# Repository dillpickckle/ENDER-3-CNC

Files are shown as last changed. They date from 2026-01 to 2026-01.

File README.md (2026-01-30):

This is an affordable mini CNC mill built from Ender 3 parts. It’s suitable for tasks such as milling, engraving, drawing, and PCB fabrication. The machine is driven by NEMA 17 motors, belts, and two lead screws. It uses an old Dremel that I had lying around as a spindle, and I also made an enclosure out of acrylic and plywood. It use klipper software to run, with a "Klipperized" post-processor to make work on Fusion 360 CAM. Credit to @IMLAB, @SGD_Knuffel, and the team at Ender CNC for providing most of the printables. I used a mix of those files to create an Ender-3 CNC that I felt was most optimized. I made this so I can level up my future projects with acrylic and aluminum parts without having to pay a bunch to get them milled. I also hope to continue working on improving those files in the coming weeks and possibly even mill the sides out of aluminum. Other than using those files, I did not follow any specific guide and did everything else myself. 

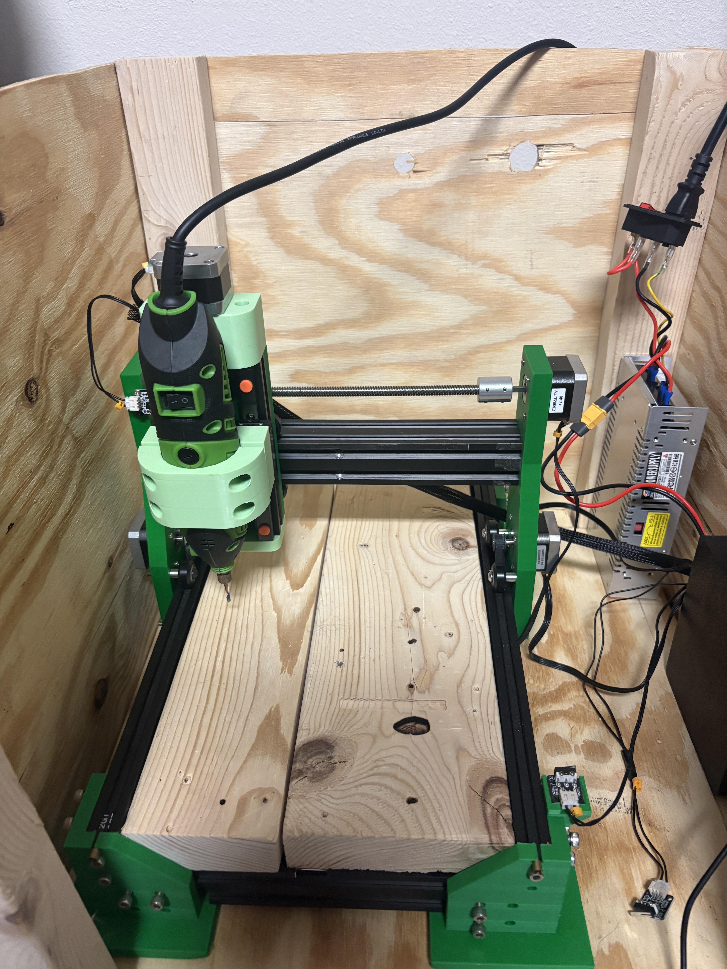
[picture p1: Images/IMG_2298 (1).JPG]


Wiring Diagram 

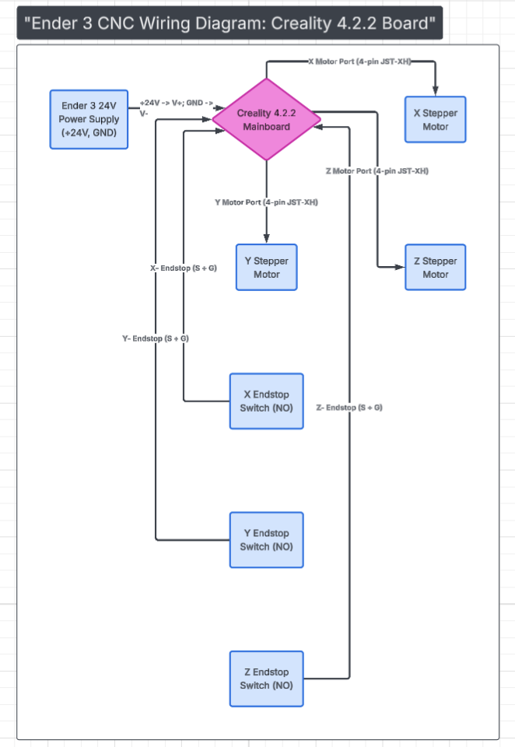
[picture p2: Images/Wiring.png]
Wiring


As you can see, it's pretty simple. Just connect the xyz ports to their respective motors and do the same with the endstops. Also, make sure to connect the board to the ender power supply. 

BOM: 

1 x Ender 3 

2 x Linear Rails 150mm MGN12H [Link for Amazon](https://www.amazon.com/uxcell-Sliding-Carriage-Plastic-Printers/dp/B0D54L8LH4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)

1 x  Mscrew assortment kit  [Link for Amazon](https://www.amazon.com/uxcell-Sliding-Carriage-Plastic-Printers/dp/B0D54L8LH4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)

1 x Brass heat threaded insert assortment kit [Link for Amazon](https://www.amazon.com/Ktehloy-Threaded-Assortment-Printing-Components/dp/B0CLKDPN65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)

32 x M5 T-Nuts [Link for Amazon](https://www.amazon.com/Glarks-European-Assortment-Aluminum-Profile/dp/B07DFG2Y4Q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)

1 x Appropriate Spindle (I used an old Dremel, which I had lying around)

2 x ball bearings (I used ones that came on ender 3 tensioner)  

2 x GT2 clip [File](https://www.thingiverse.com/thing:2523813)

All 3d Printed Parts in CAD Folder

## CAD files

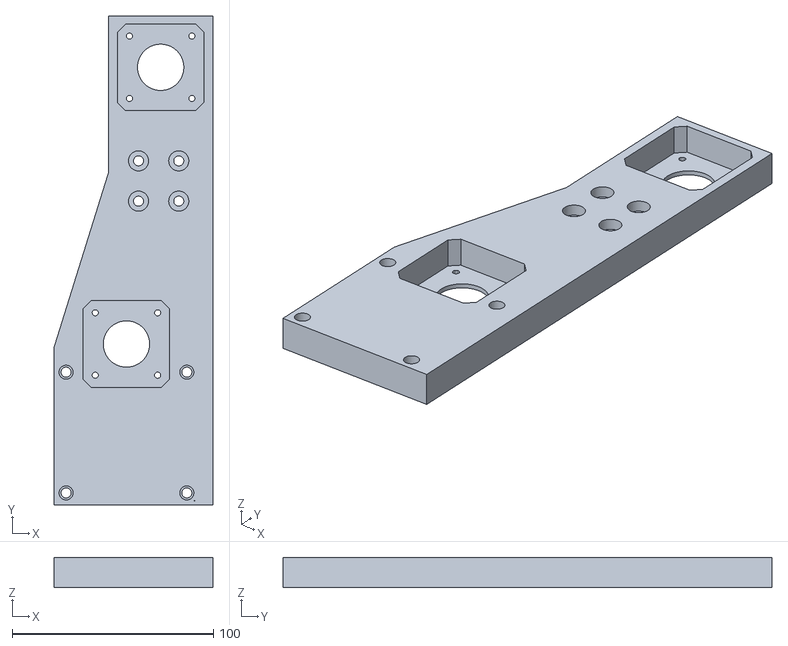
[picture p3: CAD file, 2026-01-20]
Cad/LeftSide.stl
79.0 x 243.0 x 15.0

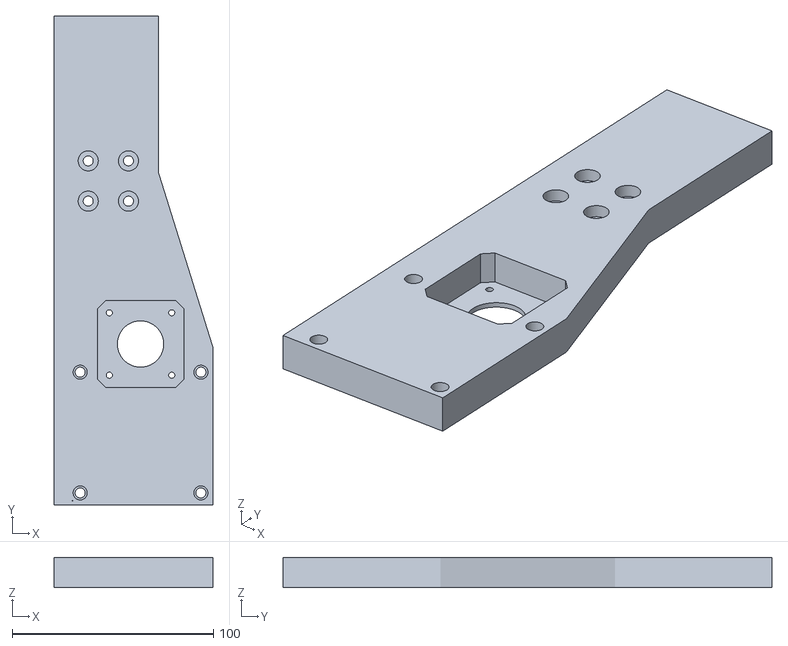
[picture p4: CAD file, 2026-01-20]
Cad/RightSide.stl
79.0 x 243.0 x 15.0

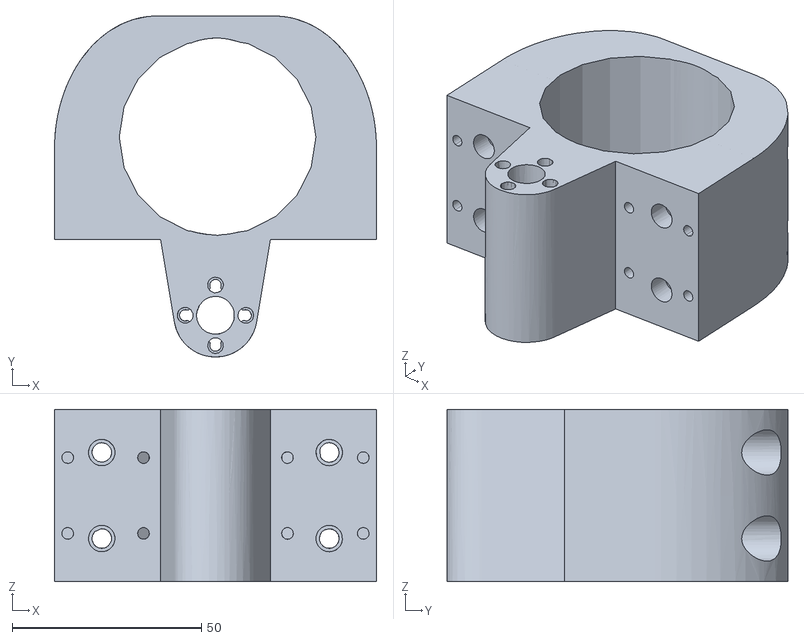
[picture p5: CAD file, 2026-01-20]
Cad/SpindleClamp.stl
85.0 x 90.0 x 45.4

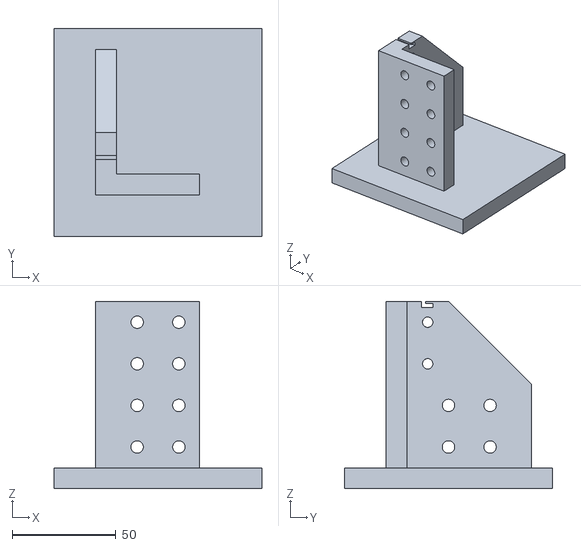
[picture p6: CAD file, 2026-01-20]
Cad/Corner2.stl
100.0 x 100.0 x 90.0

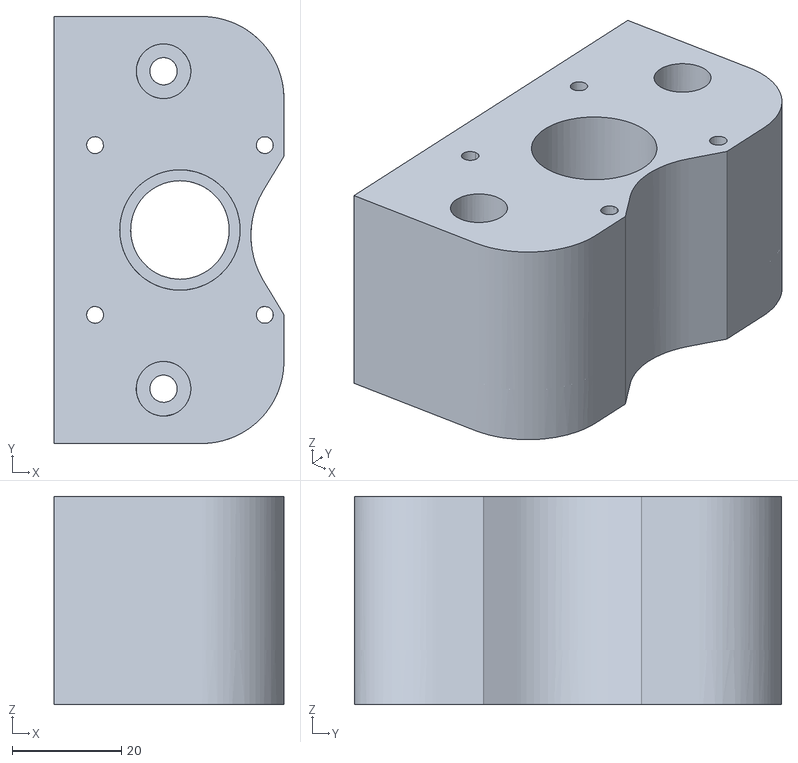
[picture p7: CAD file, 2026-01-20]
Cad/Z-MotorHalt.stl
42.0 x 78.0 x 38.0

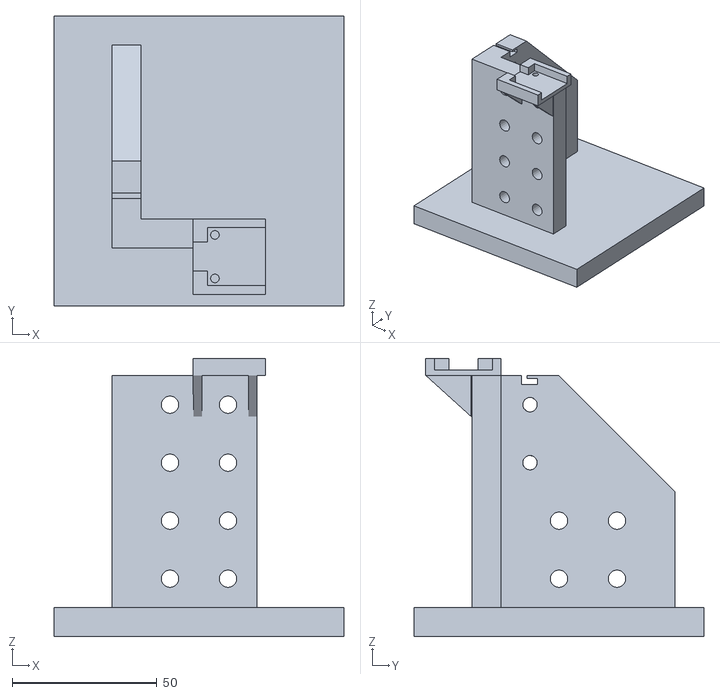
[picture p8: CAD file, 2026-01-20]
Cad/CornerWithEndstop.stl
100.0 x 100.0 x 96.0

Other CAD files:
Cad/Corner.stl
Cad/Cad, I Made/Backbracket.f3d
Cad/Cad, I Made/HANDLE.f3d
Cad/Cad, I Made/SENSOR BRACKET.f3d
Cad/Cad, I Made/Spoilboard.f3d

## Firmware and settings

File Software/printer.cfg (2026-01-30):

# This file contains pin mappings for the Creality "v4.2.7" board. To
# use this config, during "make menuconfig" select the STM32F103 with
# a "28KiB bootloader" and serial (on USART1 PA10/PA9) communication.

# If you prefer a direct serial connection, in "make menuconfig"
# select "Enable extra low-level configuration options" and select
# serial (on USART3 PB11/PB10), which is broken out on the 10 pin IDC
# cable used for the LCD module as follows:
# 3: Tx, 4: Rx, 9: GND, 10: VCC

# Flash this firmware by copying "out/klipper.bin" to a SD card and
# turning on the printer with the card inserted. The firmware
# filename must end in ".bin" and must not match the last filename
# that was flashed.

# See docs/Config_Reference.md for a description of parameters.

[stepper_x]
step_pin: PC2
dir_pin: PB9
enable_pin: !PC3
microsteps: 16
rotation_distance: 16
endstop_pin: ^PA5
position_endstop: 0
position_max:241
homing_speed: 10

[stepper_y]
step_pin: PB8
dir_pin: !PB7
enable_pin: !PC3
microsteps: 16
rotation_distance: 20
endstop_pin: ^PA6
position_endstop: 0
position_max: 304
homing_speed: 10

# [stepper_y1]
# step_pin: PB4
# dir_pin: PB3
# enable_pin: !PC3
# microsteps: 16
# rotation_distance: 35



[stepper_z]
step_pin: PB6
dir_pin: PB5
enable_pin: !PC3
microsteps: 16
rotation_distance: 3
endstop_pin: ^PA7
#position_endstop: 0.0
position_max: 115
homing_speed: 50
homing_positive_dir: 0
[fan]
pin: PA0

[mcu]
serial: /dev/serial/by-id/usb-1a86_USB_Serial-if00-port0
restart_method: command

[printer]
kinematics: cartesian
max_velocity: 300
max_accel: 3000
max_z_velocity: 5
max_z_accel: 100

[include mainsail.cfg]

[gcode_arcs]
resolution: 0.25
#*# <---------------------- SAVE_CONFIG ---------------------->
#*# DO NOT EDIT THIS BLOCK OR BELOW. The contents are auto-generated.
#*#
#*# [stepper_z]
#*# position_endstop = 38.000
